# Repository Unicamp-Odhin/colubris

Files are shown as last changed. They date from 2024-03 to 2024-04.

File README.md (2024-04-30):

# Estação metereologica LoRaWAN | Colubris

A Colubris é uma placa de hardware aberto baseada no microcontrolador ESP32-S2 e equipada com um módulo LoRa SX1262 integrado. Além disso, ela possui um sistema de gerenciamento de bateria que permite carregar e utilizar baterias diretamente pela placa. A principal finalidade da Colubris é equipar estações meteorológicas que operarão em áreas remotas, mas ela é versátil o suficiente para ser usada em outros dispositivos que necessitem de comunicação de longo alcance.

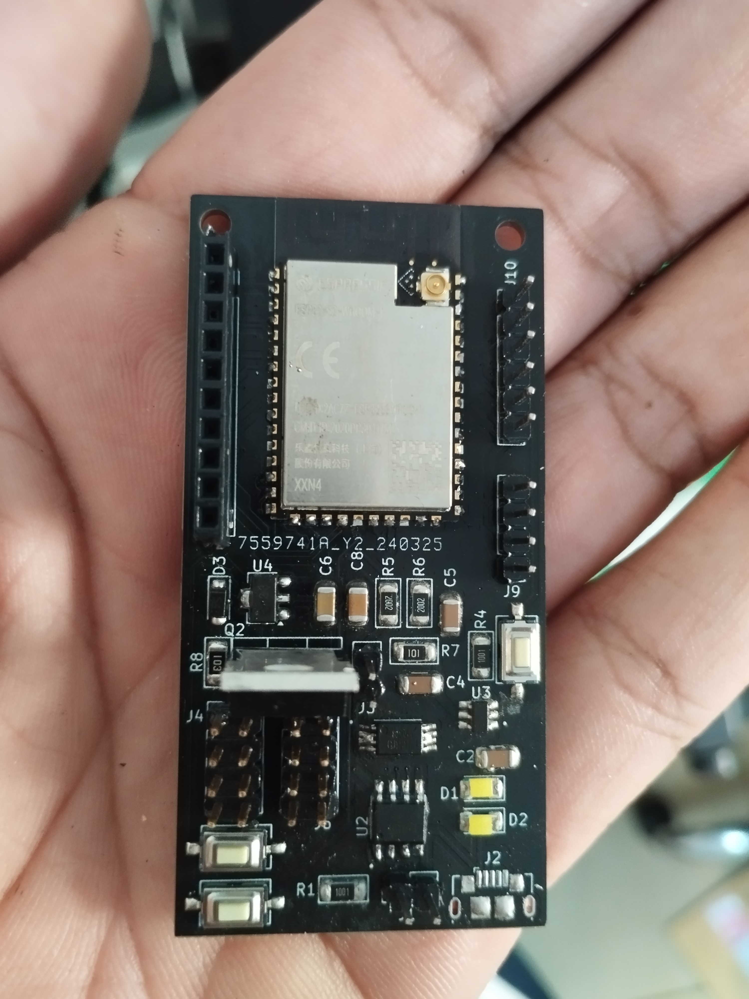
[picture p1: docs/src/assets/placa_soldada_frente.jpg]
Placa Colubris soldada


## Desenvolvedores:

Autor: Julio Nunes Avelar.

## Hardware

Principal:

- ESP32S2/ESP32
- EByte E22-900M22 (SX1262)
- TP4056
- DW01
- 8205A
- Mosfet Canal P IRF4905 ou IRF9540
- Diodo Schottky 1n5819
- PCB impressa
- Botões
- Resistores diversos
- Capacitores diveros

A lista completa pode ser consultada na [documentação](https://embarcacoes.ic.unicamp.br/colubris/build/)

Opcional:

- Modulo de Carga TP4056
- Bateria 18650 4.2V 2600mAh
- DHT22
- Sensor de Umidade do Solo
- Sensor de Nivel de Água
- Sensor de Chuva
- Sensor de Vento
- BME280
- BH1750
- Display OLED 0.96" 128x64 I2C
- Case 3D impressa em ABS

## Software

- [ESP-IDF](https://docs.espressif.com/projects/esp-idf/en/latest/esp32/)

## Pré-requisitos:

- [ESP-IDF](https://docs.espressif.com/projects/esp-idf/en/latest/esp32/get-started/).

Você precisara do ESPIDF para compilar e gravar o Firmware na Placa.

## Configurações:

O Firmware está localizado em colubris, para acessar o diretorio use:

```bash
cd colubris
```

## Menu config:

Para gravar o firmware será necessario realizar alguns ajustes no menu config.

Para "invocar" o ESPID, utilize:

```bash
get_idf
```

Após invocar o IDF, nó diretorio, será necessario escolher o MCU, para utilizar o ESP32S2, utilize:

```bash
idf.py set-target esp32s2
```

Se você estiver usando a extensão do VS-Code, existe uma opção para isso no menu inferior (Elá tem uma caixa com engrenagens como icone e do lado esta escrito esp32 ou esp32s2).

Após escolher o MCU, sera necessario realizar algumas configurações no menu config.

Para acessar o menuconfig utilize:

```bash
idf.py menuconfig
```

ou utilize a opção da extensão do VS-Code (Esta opção também está no menu inferior e tem como icone uma unica engrenagem),

Após acessar menuconfig, configure as seguintes opções:

- Configure a flash com 80mhz.
- Coloque a flash com tamanho minimo de 4 MBs.
- Escolha uma tabela de partições personalizadas.
- Coloque a frequencia da CPU em 240mhz.
- Habilite o https_client.
- Habilite a calibração do ADC.
- Habilite o componente esp_https_server.

Após realizar essas configurações, salve e saia.

## Gravando:

Para realizar a gravação primeiro será necessario realizar a compilação do firmware, é possivel compilar utilizando o comando

```bash
idf.py build
```

Após compilar o firmware para gravalo utilize:

```bash
idf.py flash
```

Caso queira utilizar o monitor serial para ver os logs, utilize:

```bash
idf.py monitor
```

Para executar tudo de uma vez, utilize:

```bash
idf.py build flash monitor
```

Esse passo a passo também pode ser realizado pela extensão do ESPIDF para o VS-Code, basta selecionar a opção: **"ESP-IDF build, flash and monitor"**.

## Organização do Projeto

O projeto é organizado em sete pastas principais:

- **3d-design**: Esta pasta contém os modelos 3D desenvolvidos para o projeto.

- **docs**: Toda a documentação dos componentes e do projeto está localizada nesta pasta.

- **colubris**: Esta pasta armazena o firmware oficial do projeto.

- **documents**: Nesta pasta, você encontrará esquemáticos compilados e datasheets relacionados ao projeto.

- **kicad-project**: Aqui estão o projeto KiCad da placa de circuito impresso (PCB) e os esquemáticos do projeto.

- **examples**: Esta pasta oferece exemplos de uso do projeto para facilitar a implementação.

O projeto foi organizado dessa forma para facilitar o acesso a diferentes aspectos e componentes do projeto.

## Duvidas e Bugs:

Em caso de alguma duvida, bug na aplicação ou sujestão, utilize o menu issues do [Gitlab](https://gitlab.com/embarcacoes/estacao-metereologica-lorawan/-/issues).

## Licença:

O hardware é disponibilizado sob a [CERN Open Hardware Licence (OHL) V2](https://gitlab.com/embarcacoes/estacao-metereologica-lorawan/-/blob/main/LICENSE.md?ref_type=heads), na versão Weakly Reciprocal [(CERN OHL-W)](https://gitlab.com/embarcacoes/estacao-metereologica-lorawan/-/blob/main/LICENSE.md?ref_type=heads). A licença pode ser encontrada na raiz do [repositório](https://gitlab.com/embarcacoes/estacao-metereologica-lorawan/-/blob/main/LICENSE.md?ref_type=heads).

O software é disponibilizado sob a [Licença MIT](https://gitlab.com/embarcacoes/estacao-metereologica-lorawan/-/blob/main/colubris/LICENSE.md?ref_type=heads), que também pode ser consultada no [GitLab](https://gitlab.com/embarcacoes/estacao-metereologica-lorawan/-/blob/main/colubris/LICENSE.md?ref_type=heads).

A documentação é disponibilizada sob a [Licença Creative Commons](https://gitlab.com/embarcacoes/estacao-metereologica-lorawan/-/blob/main/docs/LICENSE.md?ref_type=heads) e também está acessível no [GitLab](https://gitlab.com/embarcacoes/estacao-metereologica-lorawan/-/blob/main/docs/LICENSE.md?ref_type=heads).

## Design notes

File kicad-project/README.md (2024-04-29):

# Estação metereologica LoRa | Colubris

Os footprints e simbolos externos utilizados estão disponveis na pasta components. Os arquivos gerber para produção estão disponiveis na pasta gerber to order.

Na pasta 3d-design está o STL da placa.

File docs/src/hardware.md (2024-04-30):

# Hardware

## Limitações de Alimentação e Bateria

A placa pode ser alimentada com uma tensão de até 8V e suporta baterias LiPo com uma tensão máxima de até 4.2V.

## Microcontrolador

O projeto utiliza o microcontrolador ESP32-S2, fabricado pela Espressif. Esta escolha foi feita por seu alto desempenho e baixo consumo de energia, que é inferior aos modelos ESP32 e ESP32S3. Além disso, o ESP32-S2 oferece os recursos necessários para este projeto sem excessos.

Mais informações sobre o módulo estão disponíveis em: [ESP32-S2 - Espressif](https://www.espressif.com/en/products/socs/esp32-s2).

## Módulo LoRa

O módulo LoRa selecionado para o projeto é o SX1262 devido ao seu alcance superior em comparação com o SX1276 e seu menor consumo de energia. O módulo utilizado é fabricado pela Ebyte.

Mais informações sobre o módulo estão disponíveis em: [SX1262 - Ebyte](https://www.ebyte.com/en/product-view-news.aspx?id=437).

## Controlador de Carga

O projeto emprega o controlador de carga de bateria TP4056, auxiliado pelo circuito de proteção de bateria composto pelos CIs 8295A e DW01. Além disso, o circuito permite o carregamento da bateria enquanto o circuito principal é alimentado por uma fonte externa.

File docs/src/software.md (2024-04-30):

# Software

## Software do Microcontrolador

O microcontrolador é compatível com diversos frameworks de desenvolvimento, sendo os principais o [ESP-IDF](https://github.com/espressif/esp-idf), fornecido pela Espressif, e o [ArduinoCore](https://github.com/espressif/arduino-esp32), mantido pela Espressif e pela comunidade. Ambos os frameworks oferecem bibliotecas e exemplos para o uso do ESP32-S2 com o módulo LoRa.

Para o firmware oficial, adotamos o [ESP-IDF](https://github.com/espressif/esp-idf) como base para o desenvolvimento, com todo o código-fonte disponível no [GitLab](https://gitlab.com/embarcacoes/estacao-metereologica-lorawan/-/tree/main/colubris?ref_type=heads) do projeto.

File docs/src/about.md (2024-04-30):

# Sobre a Colubris

## Origem do Projeto

O projeto teve início como parte de um projeto de iniciação científica no [IFSULDEMINAS campus Muzambinho](https://muz.ifsuldeminas.edu.br/). O objetivo era usar dispositivos IoT para monitorar e automatizar processos nas áreas agrícola e pecuária. Nesse contexto, surgiu uma placa anterior à Colubris, também baseada no ESP32-S2, capaz de lidar com diversos sensores.

Com o tempo, observações sobre limitações e falhas na placa anterior levaram a diversas melhorias e correções que foram implementadas na Colubris. Essas mudanças resultaram em uma placa aprimorada, mais eficiente e robusta.

## Nome

O nome _Colubris_ é uma homenagem ao beija-flor de pescoço vermelho, conhecido cientificamente como _Archilochus colubris_. A placa recebeu esse nome devido a essa espécie ser uma ave migratória de pequeno porte, e a placa se propõe a ser igualmente pequena, energeticamente eficiente e com longo alcance, assim como o beija-flor de pescoço vermelho.

## Desenvolvedor

O circuito e a placa foram projetados por Julio Nunes Avelar e estão disponíveis para uso livre sob as licenças listadas abaixo.

## Licenças

O hardware é disponibilizado sob a [CERN Open Hardware Licence (OHL) V2](https://gitlab.com/embarcacoes/estacao-metereologica-lorawan/-/blob/main/LICENSE.md?ref_type=heads), na versão Weakly Reciprocal [(CERN OHL-W)](https://gitlab.com/embarcacoes/estacao-metereologica-lorawan/-/blob/main/LICENSE.md?ref_type=heads). A licença pode ser encontrada na raiz do repositório no [GitLab](https://gitlab.com/embarcacoes/estacao-metereologica-lorawan/-/blob/main/LICENSE.md?ref_type=heads).

O software é disponibilizado sob a [Licença MIT](https://gitlab.com/embarcacoes/estacao-metereologica-lorawan/-/blob/main/colubris/LICENSE.md?ref_type=heads), que também pode ser consultada no [GitLab](https://gitlab.com/embarcacoes/estacao-metereologica-lorawan/-/blob/main/colubris/LICENSE.md?ref_type=heads).

A documentação é disponibilizada sob a [Licença Creative Commons](https://gitlab.com/embarcacoes/estacao-metereologica-lorawan/-/blob/main/docs/LICENSE.md?ref_type=heads) e também está acessível no [GitLab](https://gitlab.com/embarcacoes/estacao-metereologica-lorawan/-/blob/main/docs/LICENSE.md?ref_type=heads).

## O Embarcações

O [Embarcações](https://embarcacoes.ic.unicamp.br/) é uma entidade estudantil composta por alunos da [UNICAMP](https://www.unicamp.br/). O grupo atua como um centro de estudos e desenvolvimento de sistemas embarcados. O autor deste projeto faz parte do grupo e utilizou sua infraestrutura para hospedagem de documentação, realização de testes e validação da placa.

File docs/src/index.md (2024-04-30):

# Placa para Estação Metereológica Colubris (Colubris LoRa Meteorological Station Board)

<center>
Placa Colubris Soldada
</center>

A Colubris é uma placa de hardware aberto baseada no microcontrolador ESP32-S2 e equipada com um módulo LoRa SX1262 integrado. Além disso, ela possui um sistema de gerenciamento de bateria que permite carregar e utilizar baterias diretamente pela placa. A principal finalidade da Colubris é equipar estações meteorológicas que operarão em áreas remotas, mas ela é versátil o suficiente para ser usada em outros dispositivos que necessitem de comunicação de longo alcance.

## Vantagens da Colubris

- **Hardware Aberto**: Todo o hardware e software da Colubris é disponibilizado de forma aberta, com esquemas e arquivos de fabricação disponíveis no [GitLab](https://gitlab.com/embarcacoes/estacao-metereologica-lorawan/) do projeto. A única exceção são os chips de origem proprietária usados no projeto.
- **Baixo Consumo de Energia**: A Colubris foi projetada para ter um consumo extremamente baixo, permitindo seu funcionamento com baterias e, assim, tornando-a totalmente independente da rede elétrica. Apenas algumas células solares e uma bateria de 2200 mAh são suficientes para sua operação.
- **Design Simplificado**: Com um design simplificado, a Colubris é fácil de construir sem ferramentas complexas e oferece facilidade de manutenção e modificação.
- **Tamanho Compacto**: A placa possui dimensões de apenas 70 x 35 mm, permitindo sua instalação em espaços limitados.
- **Custo Acessível**: O custo de fabricação da placa é relativamente baixo, possibilitando a produção em larga escala com poucos recursos.

## Como contribuir?

Você pode contribuir de várias maneiras:

- **Reportando bugs**: Identifique problemas de hardware e software e registre-os na seção de [_Issues_](https://gitlab.com/embarcacoes/estacao-metereologica-lorawan/-/issues) do GitLab do projeto.

- **Aprimorando o design**: Colabore com versões futuras do design da placa, acessando e modificando os arquivos do projeto KiCad disponíveis no GitLab.

- **Fornecendo exemplos e aplicações**: Compartilhe exemplos de software e aplicações para a placa, incluindo aprimoramentos para o firmware principal.

Sua participação é valiosa para o desenvolvimento contínuo do projeto.

## Entre para a Comunidade:

- [Grupo no Telegram](https://t.me/+PdSj1sTUFSIyOGVh)

Esse site e licenciado sobre licença [CC-BY-SA-4.0](https://gitlab.com/embarcacoes/estacao-metereologica-lorawan/-/blob/main/docs/LICENSE.md?ref_type=heads)

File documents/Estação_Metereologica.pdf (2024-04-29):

# Desenvolvendo uma estação Meteorológica totalmente Open-source

## Julio Nunes Avelar

## 3 de agosto de 2023

Resumo

O projeto tem como objetivo o desenvolvimento de uma Estação Meteorológica automática totalmente open-source para fins didáticos, com capacidade de coletar dados do ambiente, como temperatura e umidade, e transmitir essas informações em tempo real através de alguma rede de comunicação sem fio. A Estação Meteorológica será construída utilizando hardware e softwares open-sources e tem como objetivo desenvolver um dispositivo de fácil acesso e aquisição por meio de um desenvolvimento colaborativo e de baixo custo. Ao longo do desenvolvimento do projeto, serão realizados diversos testes com o objetivo de validar a capacidade da Estação Meteorológica de resistir a ambientes hostis e instáveis, ao mesmo tempo em que fornece dados precisos e confiáveis. Espera-se que, ao final do projeto, a Estação meteorológica esteja pronta para uso em ambiente real, com a possibilidade de utilizar a tecnologia desenvolvida em futuros projetos e pesquisas.

Palavras-chave— Open-Source, IoT, Estação Meteorológica

## 1 Introdução

Em uma sociedade onde ter informações sobre o clima é cada vez mais necessário e crucial para a realização de diversas tarefas do dia a dia de diferentes pessoas, o surgimento de técnicas como a agricultura de precisão[3], a Agricultura 4.0[1] e as cada vez maiores mudanças climáticas impulsionaram o desenvolvimento de novas tecnologias que auxiliam o monitoramento do ambiente ao nosso redor e do clima de nosso planeta. Uma dessas tecnologias desenvolvidas que se mostrou de grande importância foi a criação de estações meteorológicas automáticas[2].
Ao contrário das estações meteorológicas convencionais, compostas por dispositivos mecânicos que reagem com a ação do tempo e do ambiente e dependem da supervisão de uma pessoa para coleta pontual dos dados, as estações meteorológicas automáticas utilizam sensores eletrônicos para coletar dados do ambiente e, dependendo de como são construídas, são capazes de operar de forma completamente autônoma, sem a necessidade de intervenção humana após a sua calibração. Todos os dados coletados por elas são transmitidos geralmente por alguma forma de comunicação sem fio, como WiFi, LoRa ou GSM.
Dispositivos como estações meteorológicas automáticas se mostram de grande utilidade, coletando e transmitindo dados do ambiente em tempo real, permitindo que os usuários dessa tecnologia tomem decisões melhores com base em informações mais precisas e recentes. No entanto, nem tudo é perfeito. Essa tecnologia ultimamente vem sendo amplamente utilizada, mas ainda possui um alto custo de aquisição e uma certa complexidade para desenvolvimento e calibração.
Para resolver esses problemas, este projeto visa desenvolver uma estação meteorológica automática capaz de coletar dados precisos do ambiente, de forma totalmente open-source[4] e de baixo custo, permitindo assim que qualquer pessoa possa estudar, modificar, estender e fabricar sua própria estação meteorológica automática.

## 2 Objetivos

## 2.1 Objetivo Geral:

Desenvolver uma estação meteorológica capaz de coletar dados do ambiente e realizar o envio desses dados de forma automática para um serviço na nuvem.

## 2.2 Objetivos Específicos:

1. Desenvolver e construir um circuito elétrico que permita o carregamento de baterias e o gerenciamento eficientemente dessas baterias;
2. Realizar a integração de diversos sensores com um microcontrolador, garantindo a coleta precisa e confiável de dados;
3. Estabelecer um sistema de comunicação sem fio capaz de atender os requisitos necessários para operação do dispositivo;
4. Realizar a integração física de todos os módulos e circuitos, garantindo um funcionamento harmonioso e eficiente do dispositivo;
5. Desenvolver uma estrutura adequada para acomodar todos os módulos e circuitos do protótipo, considerando restrições de peso, custo e fabricação;
6. Realizar a calibração dos sensores para obter dados mais precisos e confiáveis;
7. Realizar testes abrangentes de compatibilidade e integração dos componentes, garantindo que todos os sistemas funcionem de forma adequada e sem interferências;
8. Desenvolver software para a comunicação eficiente entre o dispositivo e o local onde os dados serão armazenados e tratados.
9. Desenvolver software para o armazenamento, tratamento e disponibilização dos dados fornecidos por estações meteorológicas.
10. Desenvolver um sistema de atualização via ”Over the air”(OTA), para permitir a atualização dos dispositivos de forma remota e sem acesso físico.

Além dos objetivos mencionados acima, é importante considerar a documentação detalhada de todo o processo de desenvolvimento e construção, incluindo relatórios de projeto, manuais de operação e manutenção, bem como a avaliação dos resultados obtidos e possíveis recomendações para melhorias futuras.

## 3 Justificativa

O desenvolvimento da estação meteorológica se justifica pela demanda deste tipo de dispositivo por parte de diversas pessoas e organizações, sejam elas vinculadas a universidades ou não; além disso, todo o conhecimento obtido ao longo do processo de desenvolvimento e os dados que podem vir a ser coletados pelos dispositivos podem ser muito úteis em projetos e pesquisas futuras, com todo o embasamento obtido ao longo do projeto sendo útil para a comunidade acadêmica ao longo de um longo período de tempo; por último, não menos importante, o desenvolvimento de uma estação meteorológica automática, completamente open-source, auxilia na democratização do acesso a tecnologias de grande importância para o desenvolvimento de atividades como a agricultura e pesquisas sobre o clima, além de permitir um desenvolvimento totalmente colaborativo e de baixo custo, permitindo assim que pessoas comuns sem acesso a grandes quantidades de recursos materiais ou humanos estejam contribuindo com o projeto.

## 4 Metodologia

Trata-se de um projeto com viés tecnológico e desenvolvimento de forma exploratória, envolvendo procedimentos experimentais e empíricos. A elaboração do dispositivo ocorrerá mediante a fabricação e testes de diversos protótipos e dispositivos, os quais permitirão a coleta de uma variedade de dados durante essa fase experimental. Essas informações serão posteriormente analisadas para avaliar o desempenho, eficácia e viabilidade de implementação no dispositivo final.
Os protótipos destinados aos testes serão concebidos com base em fundamentação teórica e experiências anteriores no desenvolvimento de dispositivos eletrônicos.
Para realizar o desenvolvimento do projeto, serão adotados os seguintes procedimentos:
1. Aprofundamento dos estudos sobre microcontroladores e arquitetura de computadores;
2. Estudo sobre transmissão de dados através de redes sem fio;
3. Construção de protótipos de hardware e software;
4. Programação de placas de prototipagem, como módulos de desenvolvimento, para realizar testes de integração;
5. Desenvolvimento de uma estrutura física para a acomodação e proteção dos componentes do dispositivo;
6. Integração do hardware desenvolvido à estrutura do dispositivo;

7. Integração do software de todos os módulos do dispositivo;
8. Realização de testes em bancada com o dispositivo desenvolvido;
9. Realização de testes em ambiente controlado para analisar o comportamento do dispositivo em condições específicas;
10. Elaboração de artigos científicos e apresentação de resultados em eventos acadêmicos.

## 5 Resultado esperados

Espera-se que ao final do projeto já se tenha concluído o desenvolvimento da estação meteorológica, com a mesma já estando operando em fase de testes ou produção. Espera-se que todo o conhecimento obtido e todas as tecnologias desenvolvidas ao logo do projeto possam ser utilizados em projetos e pesquisas futuras.

## 6 Orçamento

Durante o decorrer do projeto, alguns equipamentos utilizados serão fornecidos pela estrutura da universidade, enquanto outros já estão disponíveis para o desenvolvedor do projeto. Entretanto, é essencial ressaltar que a aquisição dos componentes requer recursos adicionais, uma vez que muitos deles ainda precisam ser adquiridos. O desenvolvedor já possui uma parte dos componentes necessários, o que pode reduzir os custos de aquisição. Contudo, é preciso buscar recursos extras para garantir a obtenção de todos os componentes necessários para o desenvolvimento da Estação Meteorológica.

## Referências

[1] Silvia Maria Fonseca Silveira Massruhá — Maria Angelica de Andrade Leite. “AGRO 4.0 – RUMO
A AGRICULTURA DIGITAL”. Em: ` | | EMBRAPA (2017).
[2] Artur Sass Braga1 — Sergio Michelotto Braga — Cristóvão Vicente Scapulatempo Fernandes.
“ESTAÇOES METEORO ˜ | OGICAS AUTOM ´ | ATICAS: Relato de uma Experiência com Sensores ´
Independentes em Bacia Experimental”. Em: ABRHidro (2011).
[3] Mauro Tschiedel — Mauro Fernando Ferreira. “INTRODUÇ AÕ | A AGRICULTURA DE PRE- `
CISAO: CONCEITOS E VANTAGENS”. Em: ˜ | SciELO (2002).
[4] R.B. Silva — L.S. Leal — L.S. Alves — R.V. Brandão — R.C.M. Alves — E.V. Klering — R.P. Pezzi. “Estações meteorológicas de código aberto: Um projeto de pesquisa e desenvolvimento tecnológico”. Em: SciELO (2015).

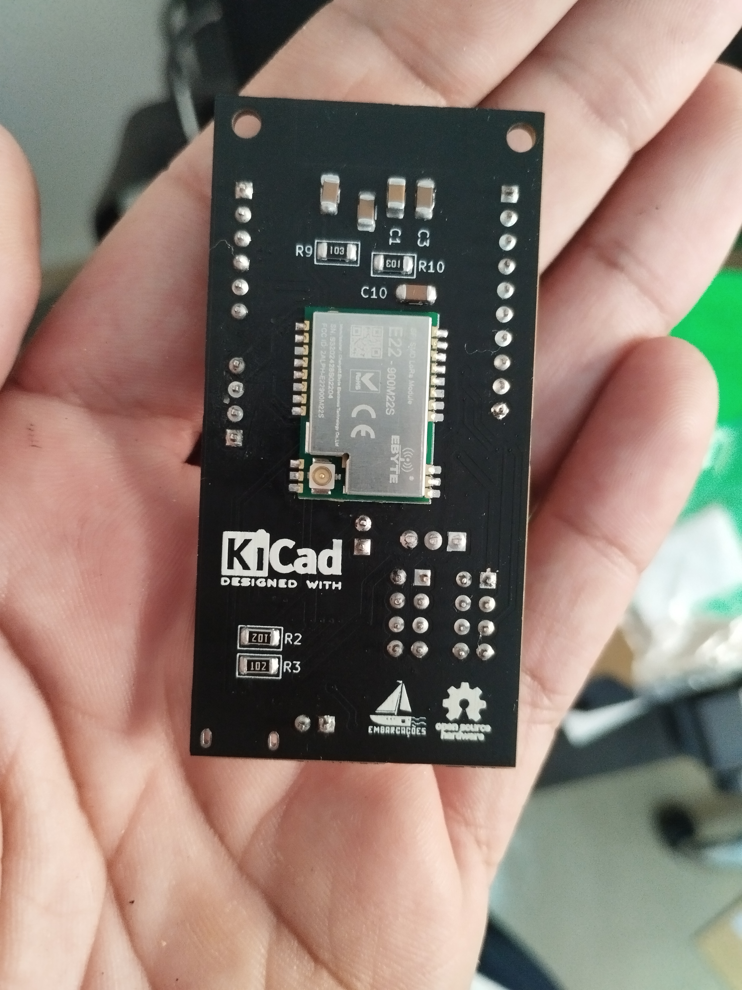
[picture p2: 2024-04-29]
docs/src/assets/placa_soldada_verso.jpg

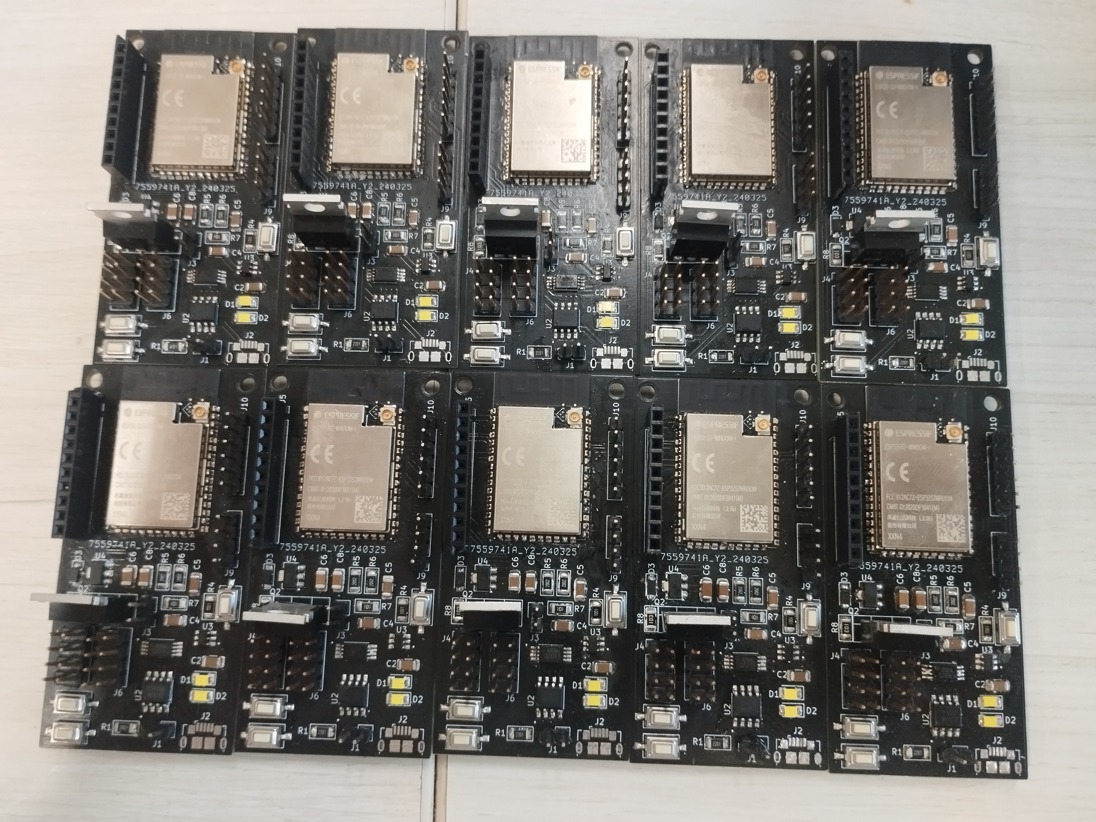
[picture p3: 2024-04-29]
docs/src/assets/10_placas_soldadas.jpg

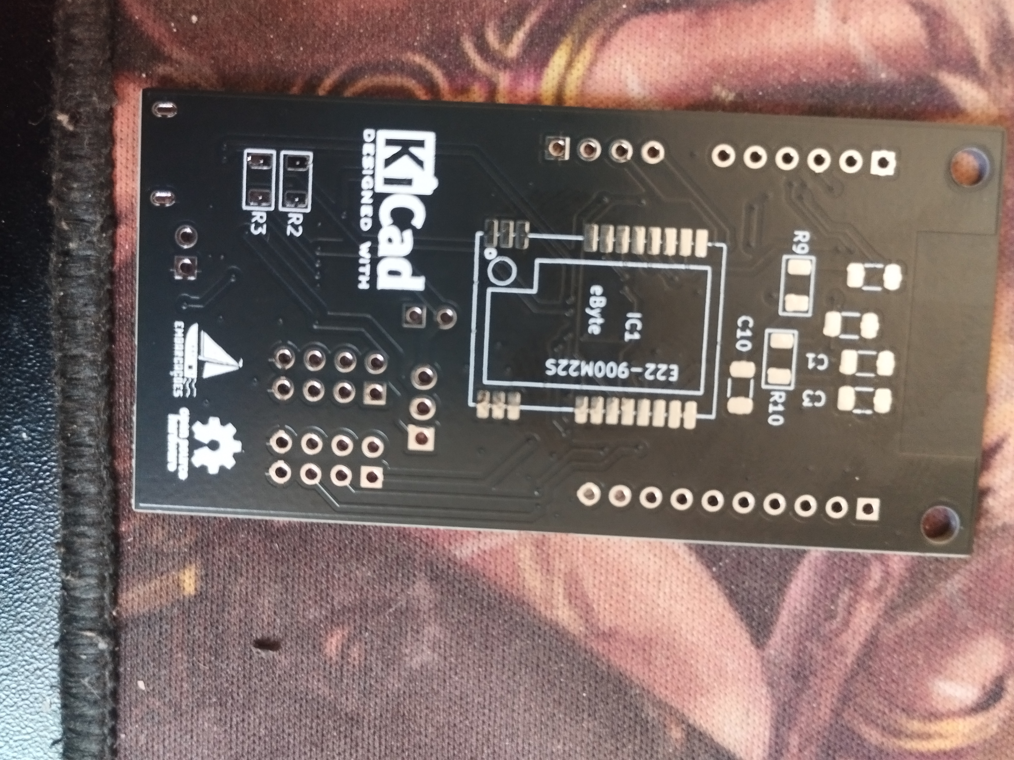
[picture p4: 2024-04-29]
docs/src/assets/pcb_verso.jpg

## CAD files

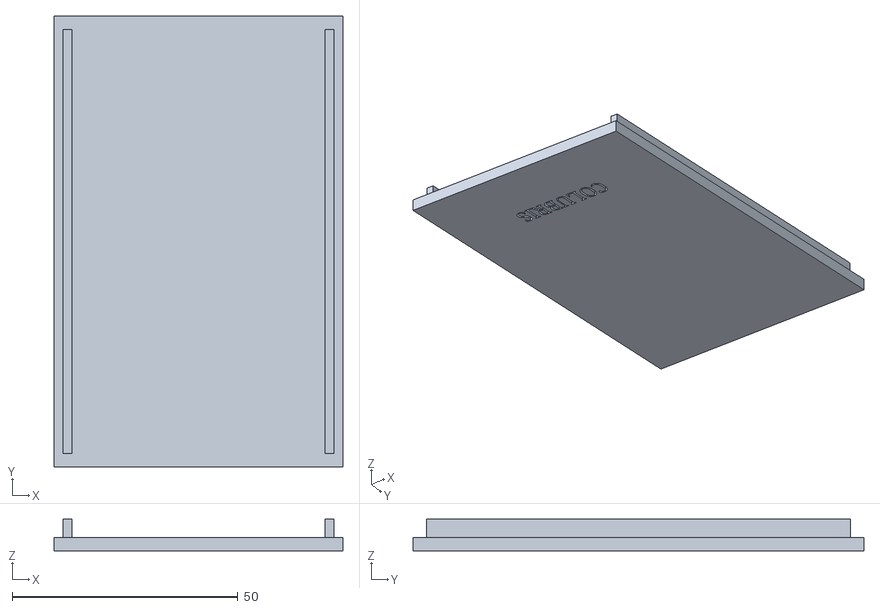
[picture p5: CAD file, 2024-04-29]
3d-design/tampa_estaco_metereologica_v1.stl
64.0 x 100.0 x 7.00

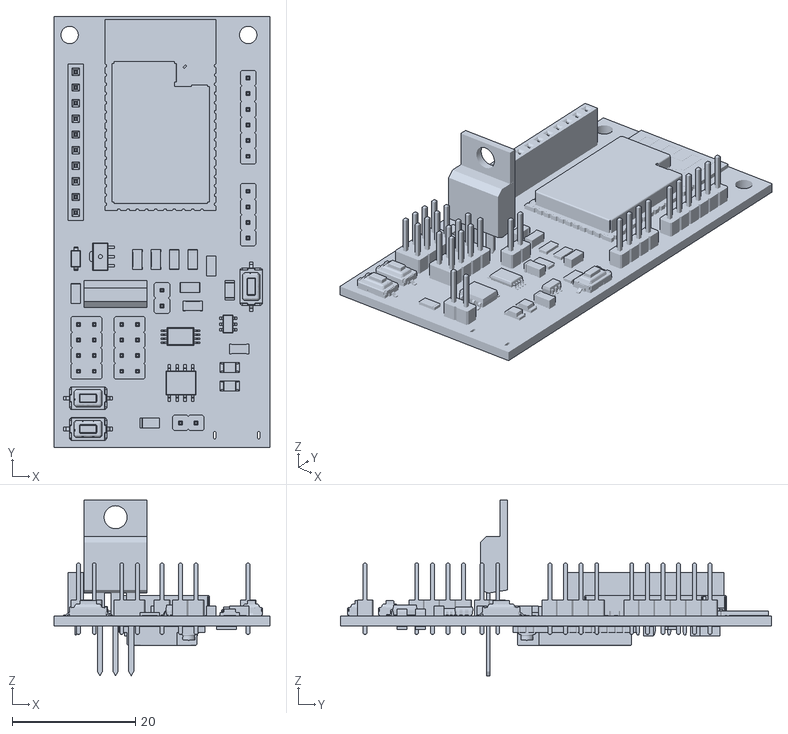
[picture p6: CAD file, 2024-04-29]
kicad-project/3d-design/ImageToStl.com_estacao_metereologica_lora.stl
35.0 x 70.0 x 28.5

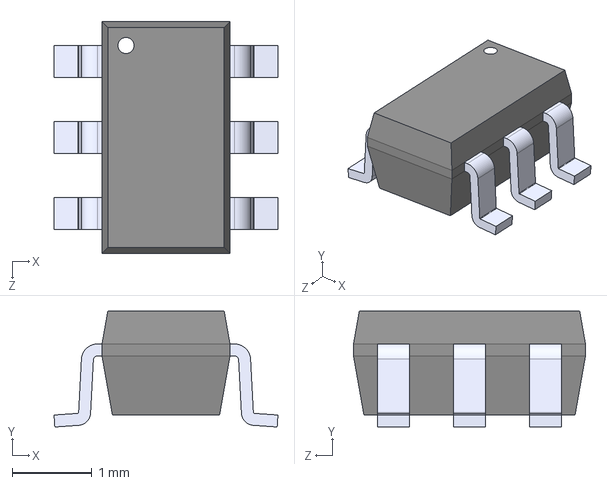
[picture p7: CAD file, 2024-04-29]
kicad-project/components/3dmodels/DW01A.step
2.80 x 1.45 x 2.90 mm

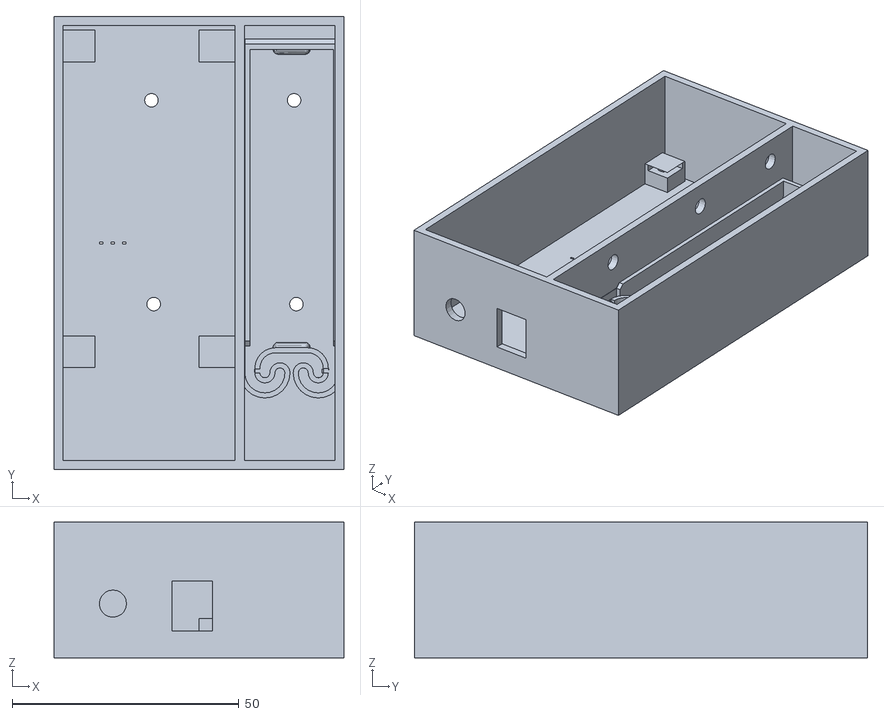
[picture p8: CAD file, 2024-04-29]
3d-design/case_estacao _metereologica_v1.stl
64.0 x 100.0 x 30.0

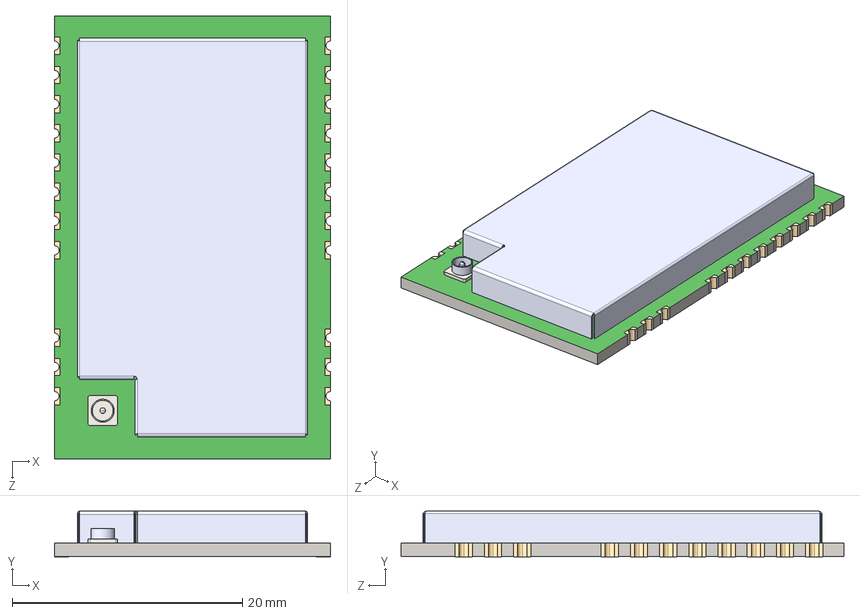
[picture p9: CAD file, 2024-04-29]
kicad-project/components/3dmodels/E22-900M30S.step
24.0 x 3.97 x 38.5 mm

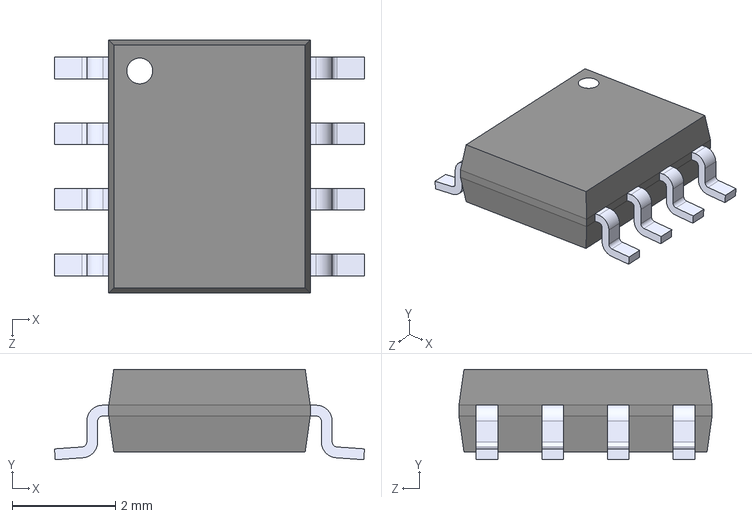
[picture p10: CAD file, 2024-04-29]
kicad-project/components/3dmodels/TP4056.step
6.00 x 1.75 x 4.90 mm

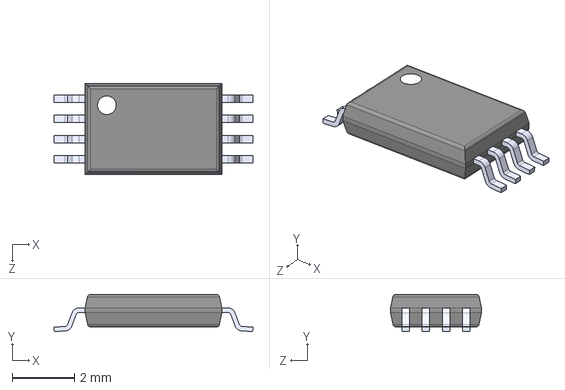
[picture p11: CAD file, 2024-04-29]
kicad-project/components/3dmodels/FS8205A.step
6.40 x 1.20 x 2.93 mm

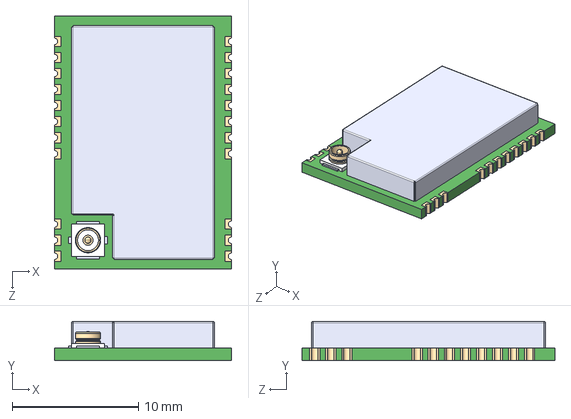
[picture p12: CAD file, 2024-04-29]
kicad-project/components/3dmodels/E22-900M22S.step
14.0 x 3.10 x 20.0 mm

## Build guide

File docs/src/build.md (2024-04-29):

# Como construir a sua Colubris

## Lista de componentes

| Nome | Quantidade |
| --- | --- |
| ESP32S2 | 1 |
| Ebyte SX1262 | 1 |
| Capacitor SMD 100nf - tamanho: 1206 | 7 |
| Capacitor SMD 10uf ~ 22uf - tamanho: 1206 | 3 |
| Resistor SMD 100R - tamanho: 1206 | 1 |
| Resistor SMD 1k - tamanho: 1206 | 3 |
| Resistor SMD 2.2k - tamanho: 1206 | 1 |
| Resistor SMD 10k - tamanho: 1206 | 3 |
| Resistor SMD 20k - tamanho: 1206 | 2 |
| LED SMD - tamanho: 1206 | 2 |
| TP 4056 | 1 |
| DW01 | 1 |
| 8205A | 1 |
| Botão SMD 3x6x2.5mm 2Pin | 3 |
| Regulador de tensão LDO HT7133 | 1 |
| Mosfet Canal P NRF 4905 | 1 |
| Diodo schottky SMD 1n 5819 - tamanho: SOD123 | 1 |
| Barra de pinos 2 pinos macho | 2 |
| Barra de pinos 4 pinos macho | 1 |
| Barra de pinos 6 pinos macho | 1 |
| Barra de pinos 10 pinos femear | 1 |

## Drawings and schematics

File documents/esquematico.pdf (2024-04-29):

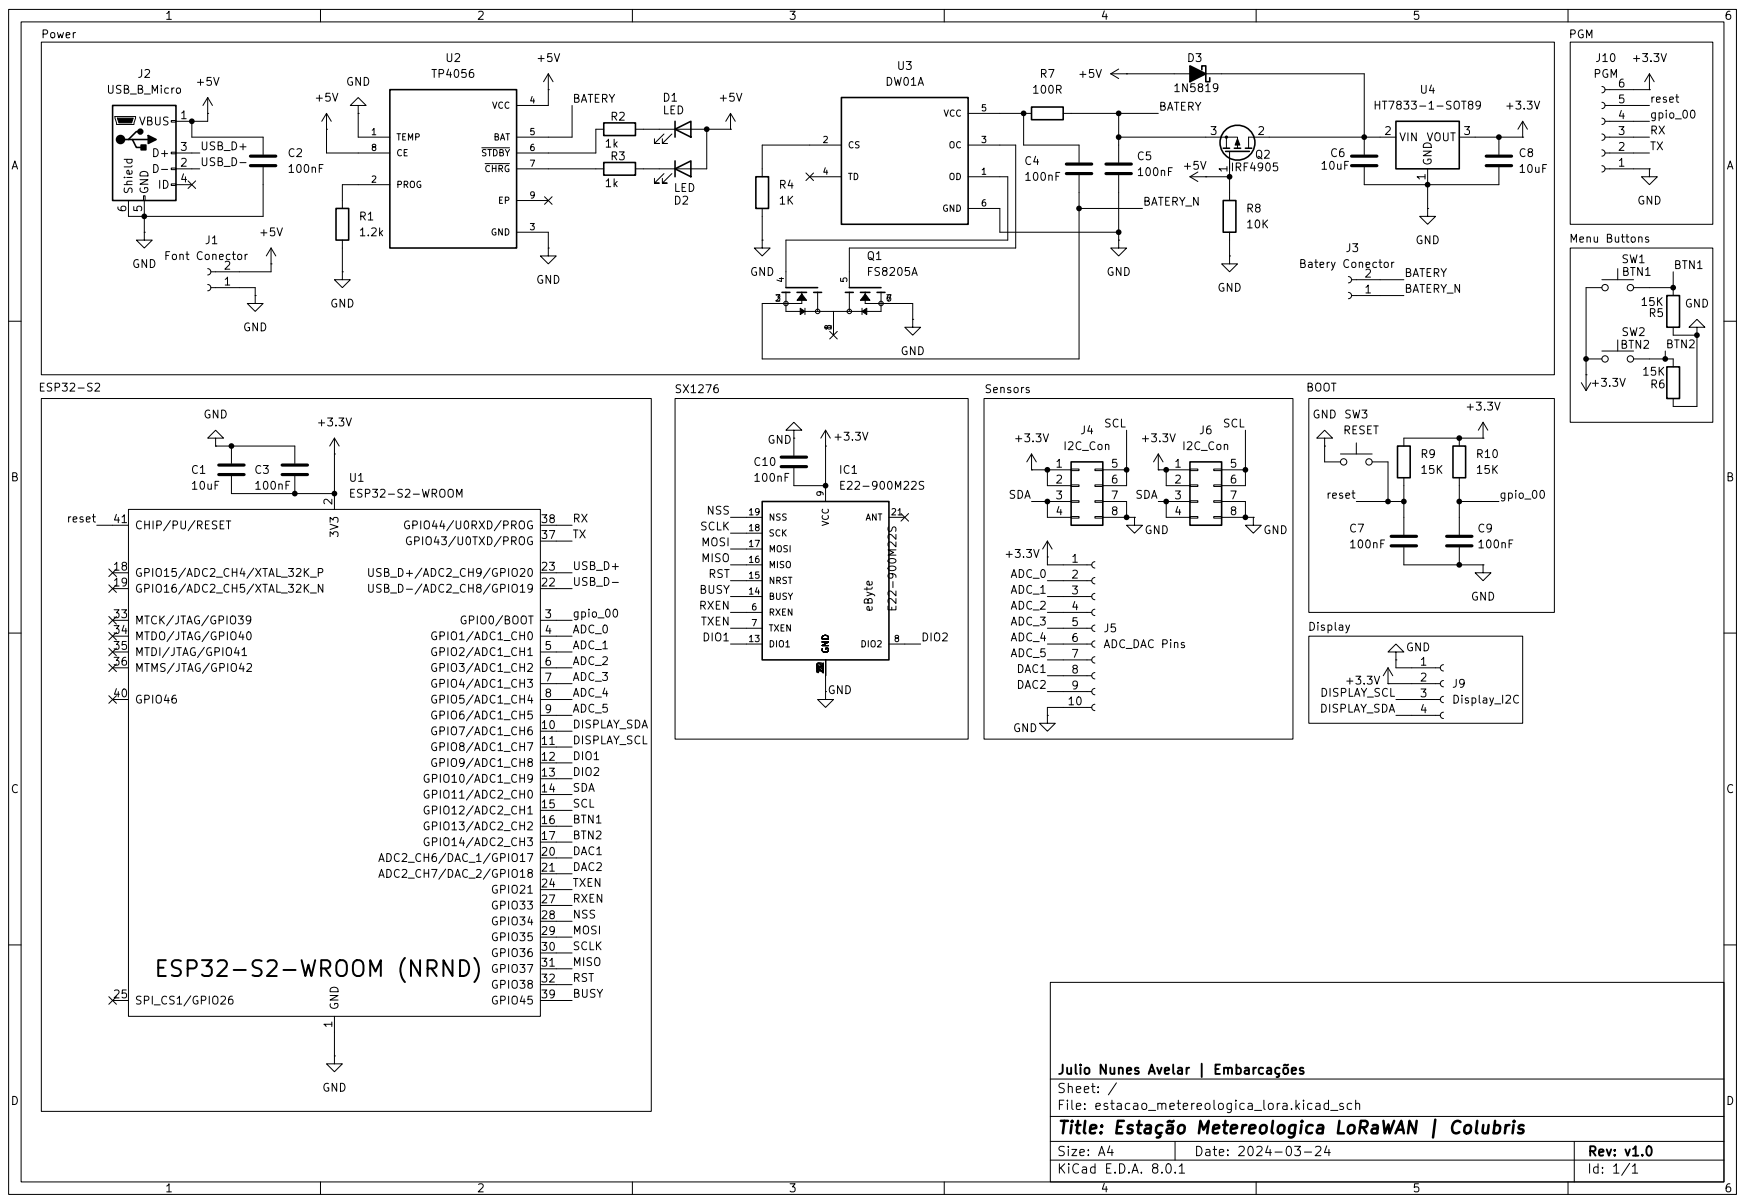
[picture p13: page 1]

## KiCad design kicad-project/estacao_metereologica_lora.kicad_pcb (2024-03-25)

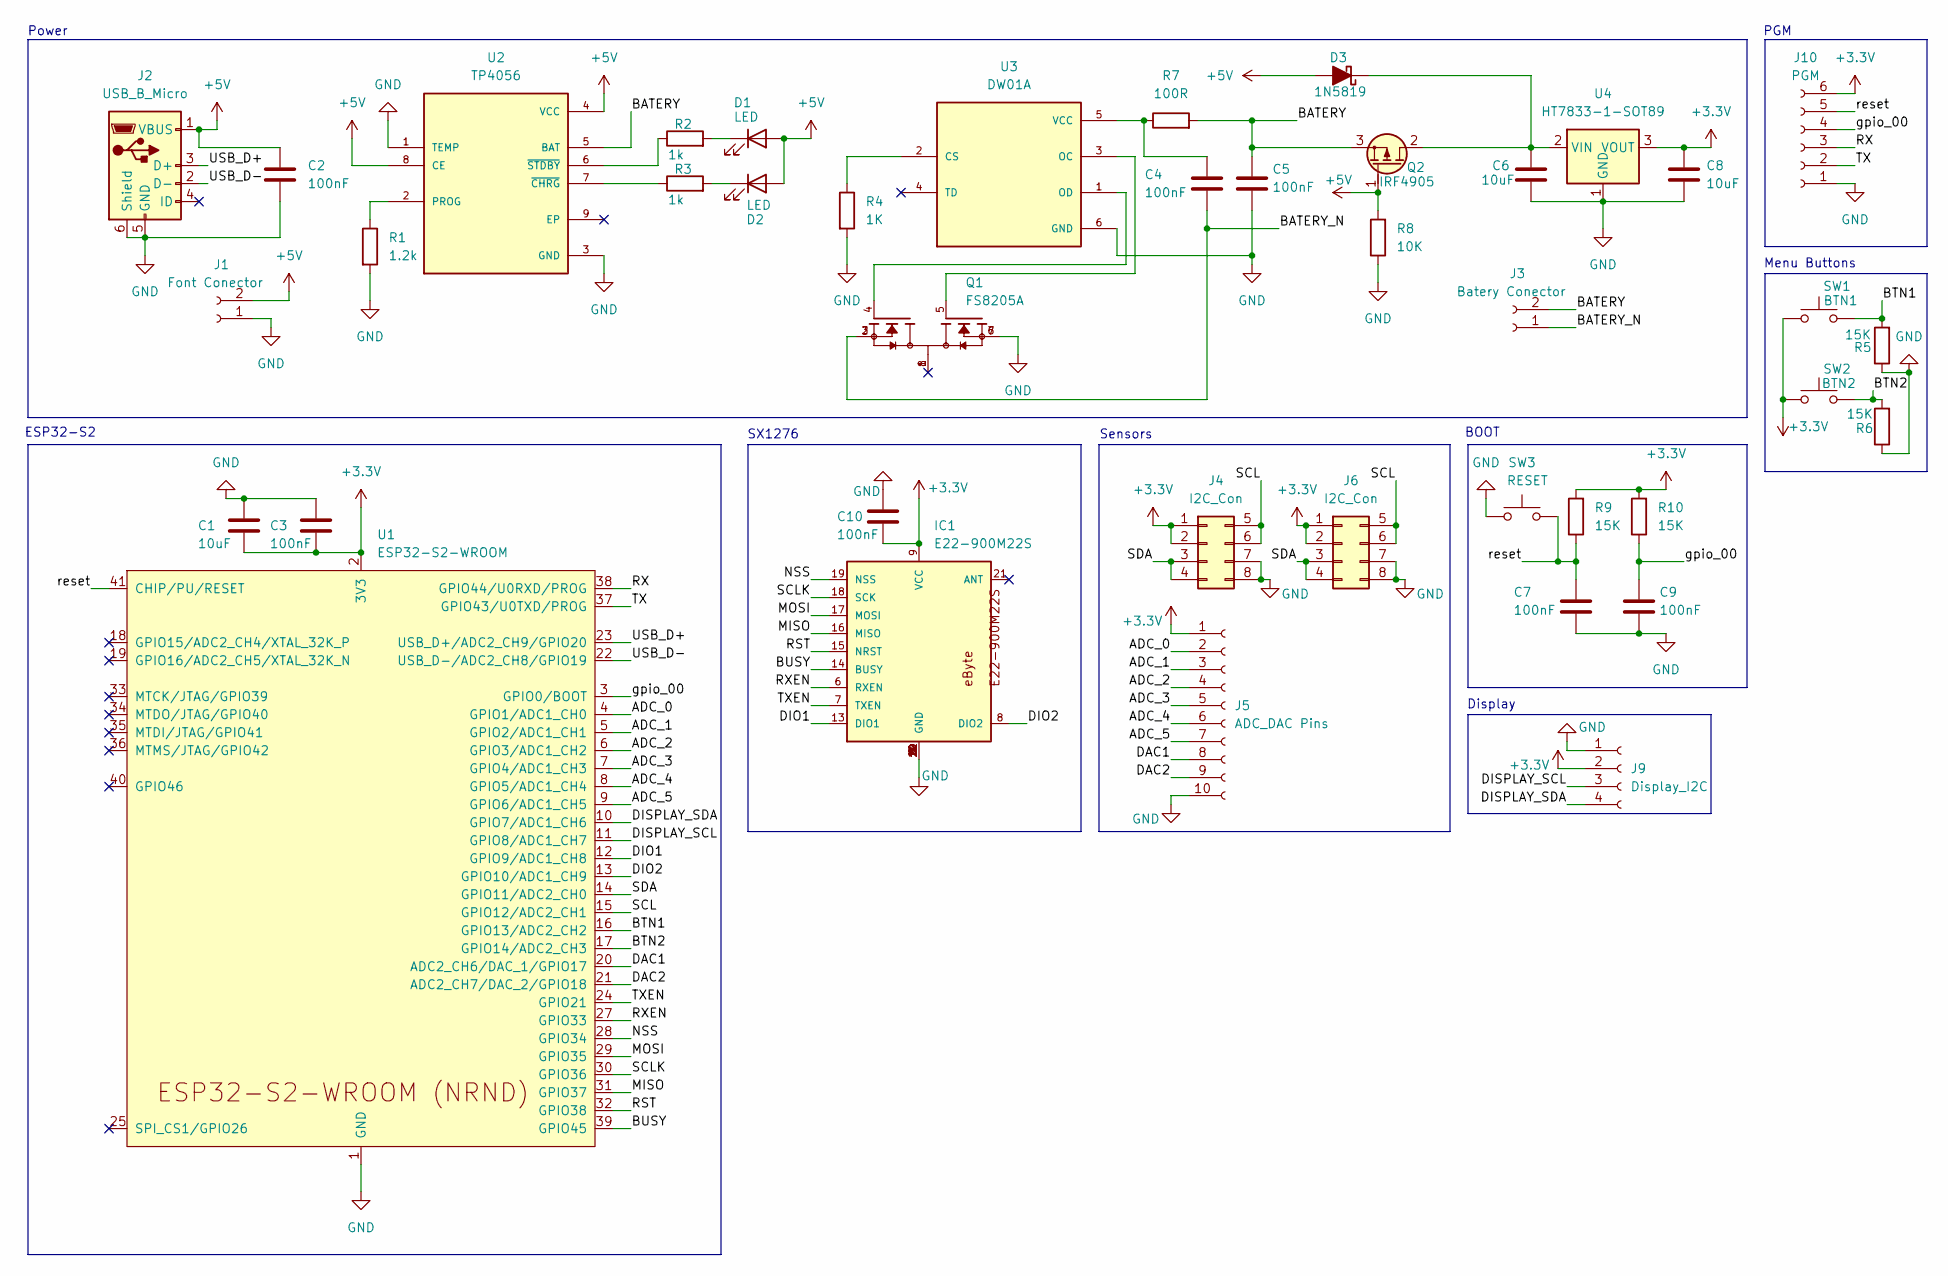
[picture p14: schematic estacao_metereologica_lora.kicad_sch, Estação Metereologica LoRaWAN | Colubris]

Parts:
C1, C6, C8: 10uF; C_1206_3216Metric
C2, C3, C4, C5, C7, C9, C10: 100nF; C_1206_3216Metric
D1, D2: LED; LED_1206_3216Metric
D3: 1N5819; D_SOD-123
IC1: E22-900M22S
J1: Font Conector; PinHeader_1x02_P2.54mm_Vertical
J2: USB_B_Micro; USB_Micro-B_GCT_USB3076-30-A
J3: Batery Conector; PinHeader_1x02_P2.54mm_Vertical
J4, J6: I2C_Con; PinHeader_2x04_P2.54mm_Vertical
J5: ADC_DAC Pins; PinSocket_1x10_P2.54mm_Vertical
J9: Display_I2C; PinHeader_1x04_P2.54mm_Vertical
J10: PGM; PinHeader_1x06_P2.54mm_Vertical
Q1: FS8205A; PARTREV 1.7
Q2: IRF4905; TO-220-3_Vertical
R1: 1.2k; R_1206_3216Metric
R2, R3: 1k; R_1206_3216Metric
R4: 1K; R_1206_3216Metric
R5, R6, R9, R10: 15K; R_1206_3216Metric
R7: 100R; R_1206_3216Metric
R8: 10K; R_1206_3216Metric
SW1: BTN1; SW_Tactile_SPST_NO_Straight_CK_PTS636Sx25SMTRLFS
SW2: BTN2; SW_Tactile_SPST_NO_Straight_CK_PTS636Sx25SMTRLFS
SW3: RESET; SW_Tactile_SPST_NO_Straight_CK_PTS636Sx25SMTRLFS
U1: ESP32-S2-WROOM
U2: TP4056; SOP127P600X175-9N
U3: DW01A; PARTREV 1.8
U4: HT7833-1-SOT89; SOT-89-3

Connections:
+3.3V: C1.2, C3.2, C8.1, C10.2, IC1.9 (VCC), J4.1, J4.2, J5.1, J6.1, J6.2, J9.2, J10.6, R9.2, R10.2, SW1.1, SW2.1, U1.2 (3V3), U4.3 (VOUT)
+5V: C2.1, D1.2 (A), D2.2 (A), D3.2 (A), J1.2, J2.1 (VBUS), Q2.1 (G), R8.2, U2.4 (VCC), U2.8 (CE)
/ADC_0: J5.2, U1.4 (GPIO1/ADC1_CH0)
/ADC_1: J5.3, U1.5 (GPIO2/ADC1_CH1)
/ADC_2: J5.4, U1.6 (GPIO3/ADC1_CH2)
/ADC_3: J5.5, U1.7 (GPIO4/ADC1_CH3)
/ADC_4: J5.6, U1.8 (GPIO5/ADC1_CH4)
/ADC_5: J5.7, U1.9 (GPIO6/ADC1_CH5)
/BATERY: C5.1, J3.2, Q2.3 (S), R7.2, U2.5 (BAT)
/BATERY_N: C4.2, J3.1, Q1.2, Q1.3
/BTN1: R5.2, SW1.2, U1.16 (GPIO13/ADC2_CH2)
/BTN2: R6.2, SW2.2, U1.17 (GPIO14/ADC2_CH3)
/BUSY: IC1.14 (BUSY), U1.39 (GPIO45)
/DAC1: J5.8, U1.20 (ADC2_CH6/DAC_1/GPIO17)
/DAC2: J5.9, U1.21 (ADC2_CH7/DAC_2/GPIO18)
/DIO1: IC1.13 (DIO1), U1.12 (GPIO9/ADC1_CH8)
/DIO2: IC1.8 (DIO2), U1.13 (GPIO10/ADC1_CH9)
/DISPLAY_SCL: J9.3, U1.11 (GPIO8/ADC1_CH7)
/DISPLAY_SDA: J9.4, U1.10 (GPIO7/ADC1_CH6)
/MISO: IC1.16 (MISO), U1.31 (GPIO37)
/MOSI: IC1.17 (MOSI), U1.29 (GPIO35)
/NSS: IC1.19 (NSS), U1.28 (GPIO34)
/RST: IC1.15 (NRST), U1.32 (GPIO38)
/RX: J10.3, U1.38 (GPIO44/U0RXD/PROG)
/RXEN: IC1.6 (RXEN), U1.27 (GPIO33)
/SCL: J4.5, J4.6, J6.5, J6.6, U1.15 (GPIO12/ADC2_CH1)
/SCLK: IC1.18 (SCK), U1.30 (GPIO36)
/SDA: J4.3, J4.4, J6.3, J6.4, U1.14 (GPIO11/ADC2_CH0)
/TX: J10.2, U1.37 (GPIO43/U0TXD/PROG)
/TXEN: IC1.7 (TXEN), U1.24 (GPIO21)
/USB_D+: J2.3 (D+), U1.23 (USB_D+/ADC2_CH9/GPIO20)
/USB_D-: J2.2 (D-), U1.22 (USB_D-/ADC2_CH8/GPIO19)
/gpio_00: C9.1, J10.4, R10.1, U1.3 (GPIO0/BOOT)
/reset: C7.1, J10.5, R9.1, SW3.2, U1.41 (CHIP/PU/RESET)
GND: C1.1, C2.2, C3.1, C5.2, C6.2, C7.2, C8.2, C9.2, C10.1, IC1.1 (GND), IC1.2 (GND), IC1.3 (GND), IC1.4 (GND), IC1.5 (GND), IC1.10 (GND), IC1.11 (GND), IC1.12 (GND), IC1.20 (GND), IC1.22 (GND), J1.1, J2.5 (GND), J2.6 (Shield), J4.7, J4.8, J5.10, J6.7, J6.8, J9.1, J10.1, Q1.6, Q1.7, R1.2, R4.2, R5.1, R6.1, R8.1, SW3.1, U1.1 (GND), U1.26 (GND), U1.42 (GND), U1.43 (GND), U2.1 (TEMP), U2.3 (GND), U3.6 (GND), U4.1 (GND)
unnamed: D1.1 (K), R2.2
unnamed: D2.1 (K), R3.2
unnamed: C6.1, D3.1 (K), Q2.2 (D), U4.2 (VIN)
unnamed: R1.1, U2.2 (PROG)
unnamed: R3.1, U2.7 (~CHRG)
unnamed: R2.1, U2.6 (~STDBY)
unnamed: R4.1, U3.2 (CS)
unnamed: Q1.5, U3.3 (OC)
unnamed: Q1.4, U3.1 (OD)
unnamed: C4.1, R7.1, U3.5 (VCC)

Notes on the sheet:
SX1276
Menu Buttons
ESP32-S2
BOOT
PGM
Power
Display
Sensors

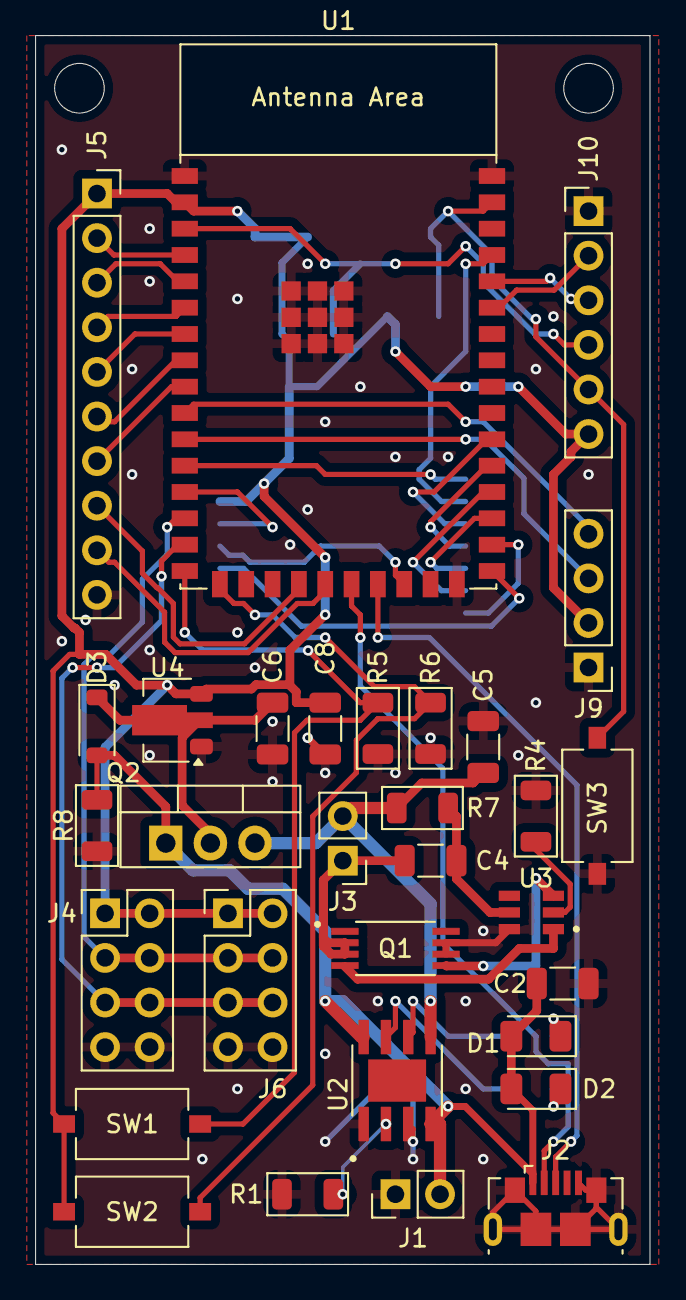
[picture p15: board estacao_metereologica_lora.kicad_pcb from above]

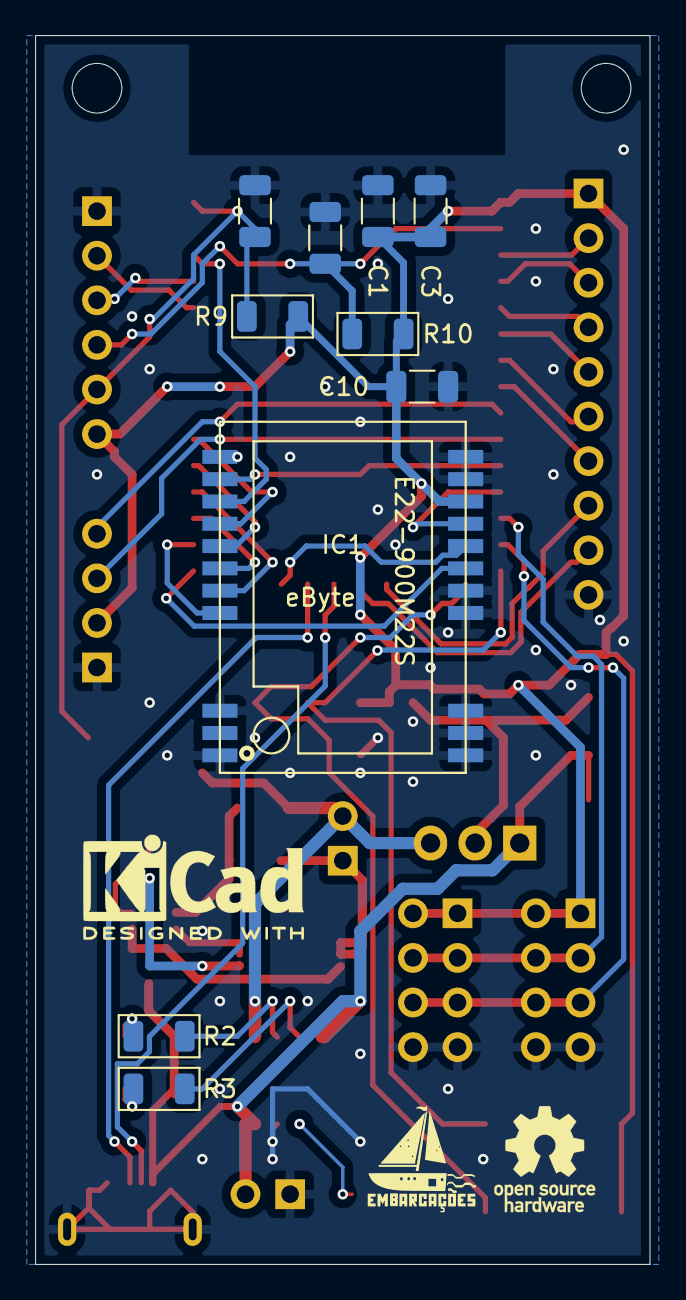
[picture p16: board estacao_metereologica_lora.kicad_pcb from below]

Board: 2 copper layers, 35.0 x 70.0 mm, 41 parts (10 on the bottom side), 45 nets.

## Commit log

2024-03-25 Iniciando projeto com esquematicos
    [estacao_metereologica_lora-B_Cu.gbr, estacao_metereologica_lora-B_Mask.gbr, estacao_metereologica_lora-B_Silks.gbr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]
2024-03-25 Atualizando esquematico
    [estacao_metereologica_lora.kicad_sch]
2024-04-29 Adicionando esquematico e componentes usados
    Adicionando PDF do esquematico, footprints, simbolos e outras coisas
    utilizadas no projeto
    [DW01A.step, E22-900M22S--3DModel-STEP-56544.STEP, E22-900M22S.step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]
2024-04-29 Reestruturando o projeto
    Colocando o design da PCB em local especifico e criando novas pastas
    [DW01A.step, E22-900M22S--3DModel-STEP-56544.STEP, E22-900M22S.step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]
2024-04-29 Continuando reestruturação
    [DW01A.step, E22-900M22S--3DModel-STEP-56544.STEP, E22-900M22S.step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]
2024-04-29 Criando novas pastas
    Criando pasta com modelos 3d, documentação, e software
    [ImageToStl.com_estacao_metereologica_lora.stl, case_estacao _metereologica_v1.stl, tampa_estaco_metereologica_v1 (1).stl]
2024-04-29 Adicionando imagens e começando a escrever documentação
    [tampa_estaco_metereologica_v1 (1).stl, tampa_estaco_metereologica_v1.stl]
2024-04-29 criand script de deploy
2024-04-29 atualizando script de deploy
2024-04-30 Adicionando licensas de software e documentação
2024-04-30 atualizando licença de software
2024-04-30 Adicionando datasheets e referencias tecnicas
    Adicionando datasheets e referencias do ESP32S2 e do SX1262
2024-06-07 alterando arquivo de configuração do MKDOCS
